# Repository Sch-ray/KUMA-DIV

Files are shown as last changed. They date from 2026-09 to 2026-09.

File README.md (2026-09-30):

# <center>KUMA-DIV
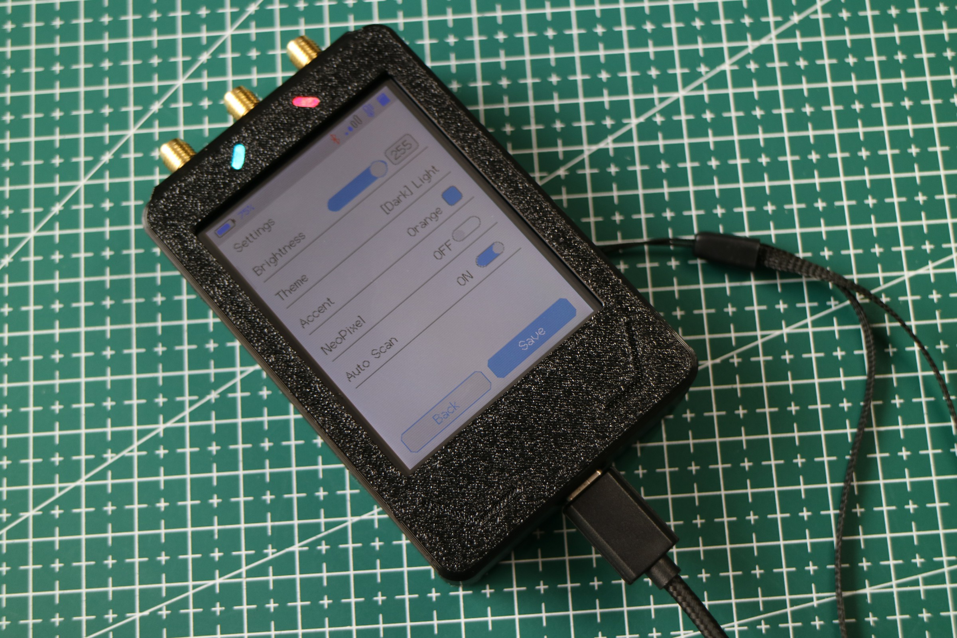
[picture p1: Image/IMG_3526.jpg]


Welcome, and thank you for your support! This is the public repository for the KUMA-DIV project.

****Project Origin****

The KUMA-DIV project is based on https://github.com/cifertech/ESP32-DIV, with the following major differences:

1. KUMA-DIV completely redefines the hardware connections, fixes several pin conflicts, and redesigns the entire PCB.

2. The design makes full use of the touchscreen, eliminating most physical buttons and significantly reducing the overall size.

3. An RGB indicator LED and a buzzer have been reintroduced.

> [!IMPORTANT]

> Disclaimer: This device is intended for lawful technical research, learning, and analysis/testing by qualified users only. (You should know what you're doing.)

****Getting Started****

There is a button on the right side of the device. Press it once briefly to power the device on, or press it twice briefly to power it off.

There are two indicator LEDs on the top of the device. The one on the left is a software-controllable RGB LED, while the one on the right is the charging indicator (red while charging, off when fully charged).

There is a Type-C port on the bottom of the device, which can be used for charging and debugging. It features an integrated CH340 USB-to-serial chip and an automatic ESP32 programming circuit.

There are six antenna ports on the top of the device. Here is what each port is used for. You can refer to the image below when installing the antennas.

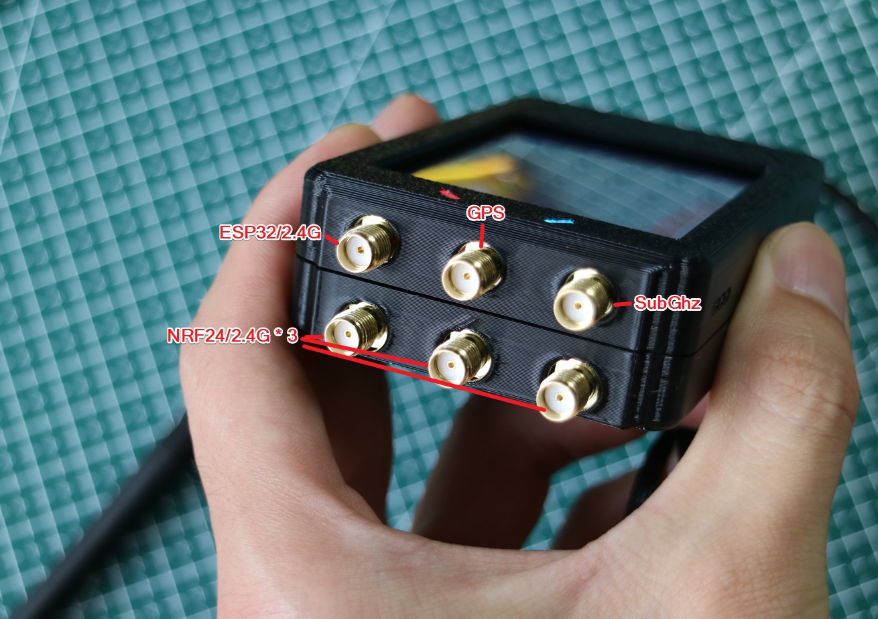
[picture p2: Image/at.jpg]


****Project Files****

[Shell_Modell](./Shell_Model)

The enclosure model files are currently available. You can now 3D-print your own enclosure and make it more stylish ⭐ and more personalized 😎!

[Software](./Software)

The source code is now available. You can build the project yourself, and a detailed compilation guide is also included in the directory 🔨!

****Contact Me****

This is my Tindie store:

[Tindie]https://www.tindie.com/stores/wensley/

If you are interested in collaboration or have suggestions regarding the project, feel free to contact me by email:

[Email]xiao_hei666@yeah.net

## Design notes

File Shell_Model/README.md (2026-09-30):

Welcome, and thank you for your support! If you have a 3D printer, you can now print your own enclosure and make it more stylish ⭐ and more personalized 😎! If you have enough time, you can also choose a finer print resolution for a more detailed result.

Next, I will explain how to assemble the enclosure. If you live in a hot climate, or if the device may be exposed to direct sunlight or high temperatures, PETG or another higher-temperature filament is recommended.

**### Before You Start Printing Your Own Enclosure:**

1. Replacing and installing the enclosure requires some hands-on skills. Any consequences caused by improper operation are your own responsibility. However, since you already have the ability to operate a 3D printer, I believe you can handle it.

2. Make sure the print bed of your 3D printer is clean and has good adhesion, as printing narrow lines and small characters places higher demands on the print bed.

**### File Description:**

This directory contains 2 main enclosure parts: the top shell, the bottom shell, and the light guides.

The light guides must be printed using transparent material.

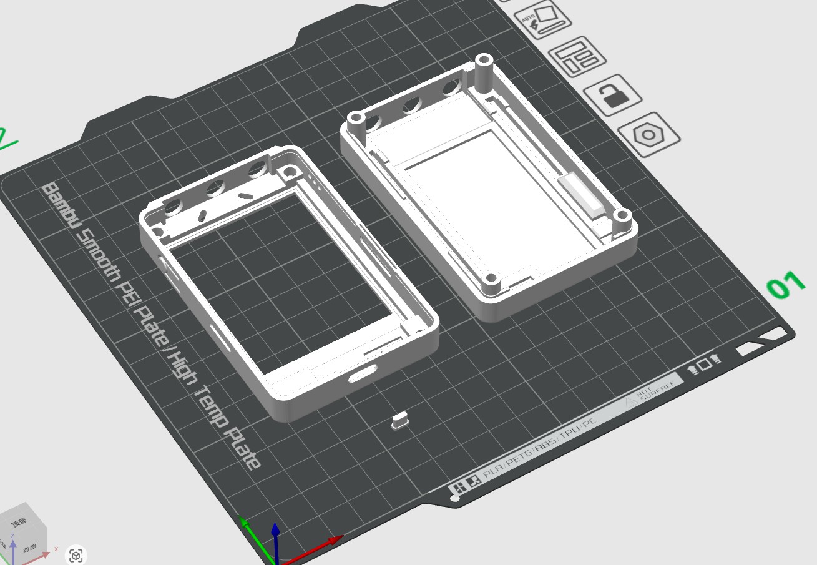
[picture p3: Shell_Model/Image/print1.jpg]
print_view_1


**### Disassembly and Assembly Instructions:**

> [!TIP]
> Before disassembly, you can touch a nearby grounded metal object or use an anti-static wrist strap to prevent electrostatic discharge from damaging the circuit board.

****1. Installing the Light Guides and Heat-Set Nuts****

Use a hammer to gently tap the light guides into the holes, making sure the front surface is flush with the enclosure. Then heat the nuts and press them into the corresponding holes. The final result should look like the pictures below:

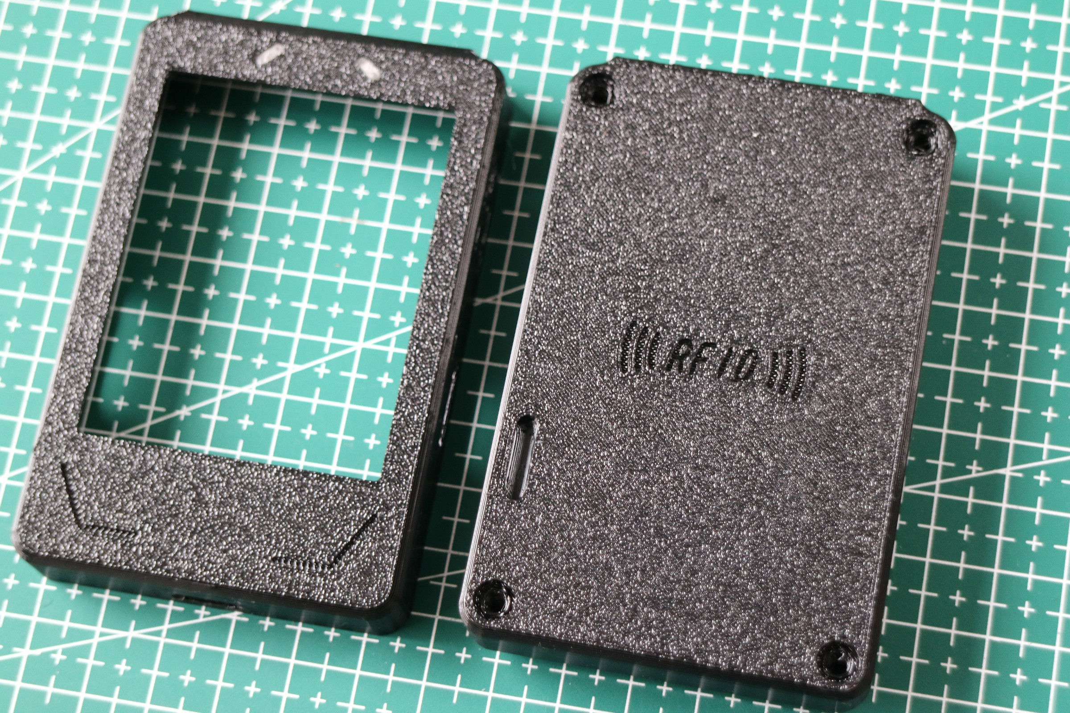
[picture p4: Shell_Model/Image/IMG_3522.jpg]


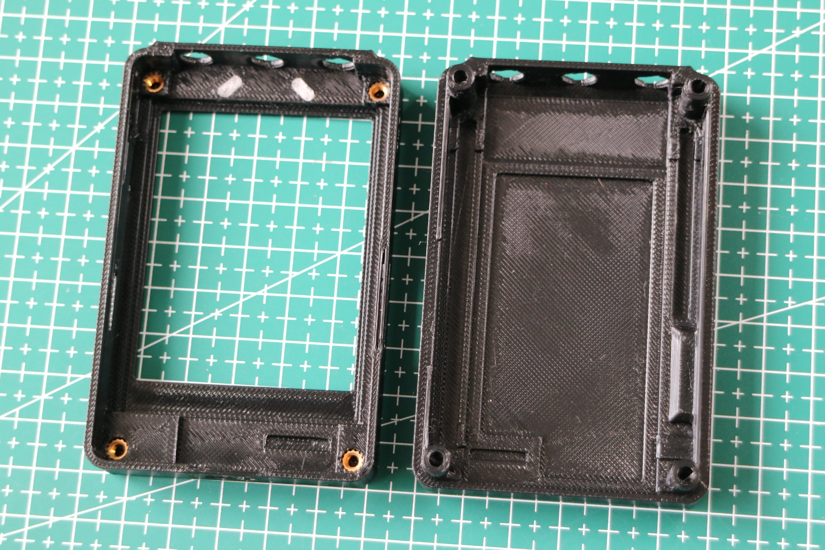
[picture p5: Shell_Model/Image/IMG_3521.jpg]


****2. Installing the RFID/NFC Module****

Before installation, you need to cut off the protruding header pins shown in the picture. As shown below, I removed two of them so you can see the difference in height.

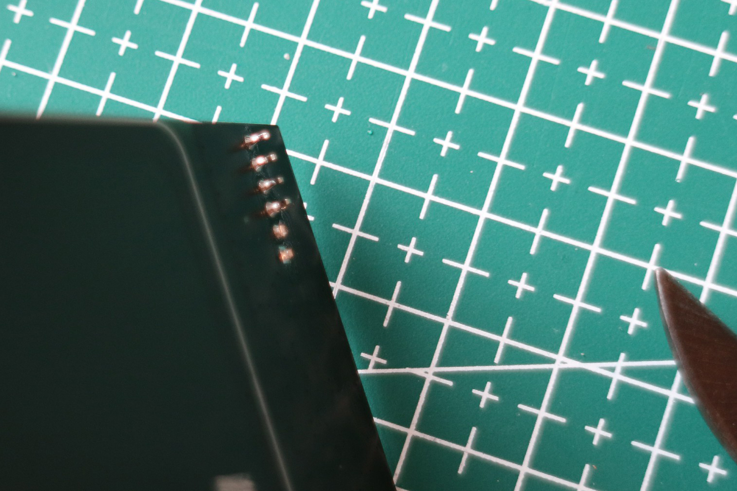
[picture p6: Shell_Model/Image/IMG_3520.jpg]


First, insert the antenna connector through the hole, then press the circuit board into the position shown in the picture. There are four clips around the circuit board. Press firmly to make sure the board is securely locked in place.

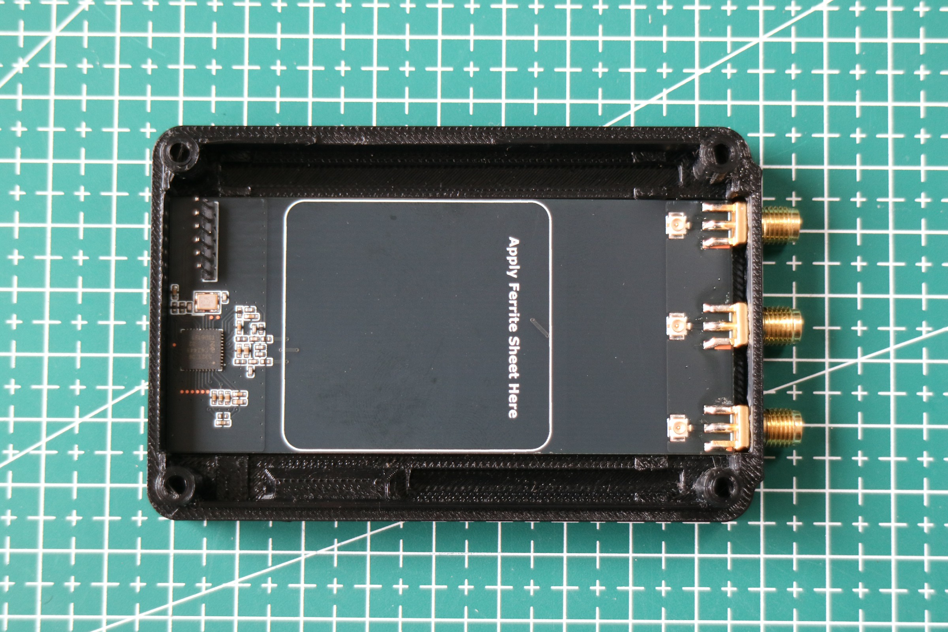
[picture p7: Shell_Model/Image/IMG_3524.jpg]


Attach the magnetic shielding sticker to the area inside the white rectangle. (The size may vary slightly; just make sure it covers the white border.) Then use double-sided tape to secure the battery to the magnetic shielding material.

<div>
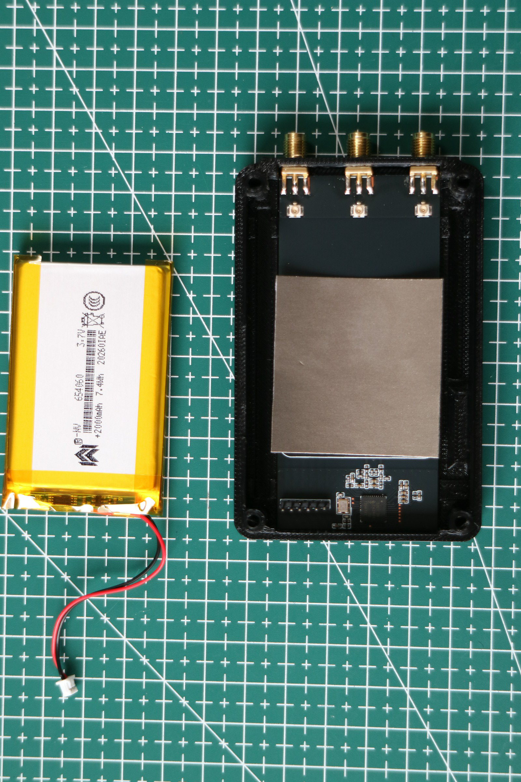
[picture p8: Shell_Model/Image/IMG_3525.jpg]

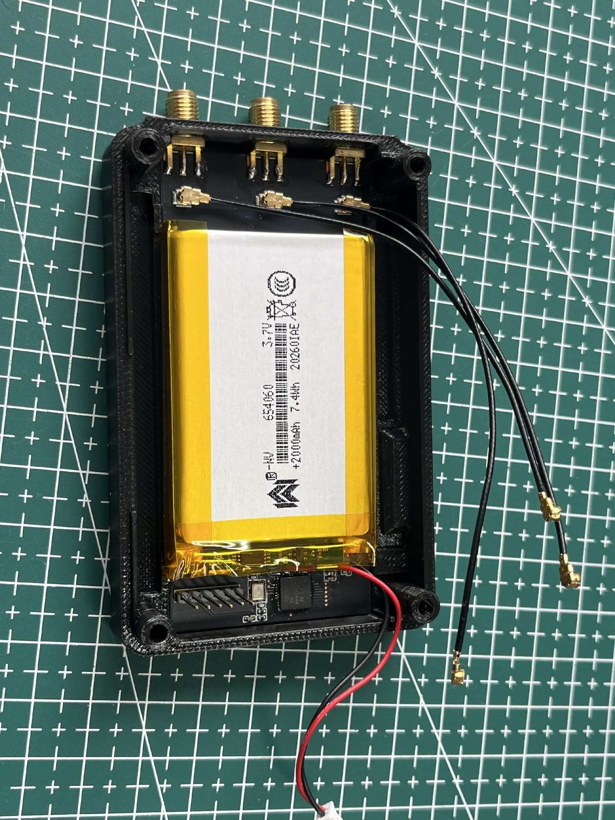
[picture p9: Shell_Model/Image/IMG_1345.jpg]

</div>

Finally, connect the antenna extension cable to the position shown in the picture.

****3. Installing the Main Board****

When installing the main board, first insert the antenna connector through the hole, then press the board into place. Make sure that the screen is properly aligned with the enclosure. Do not use excessive force, as this may damage the screen.

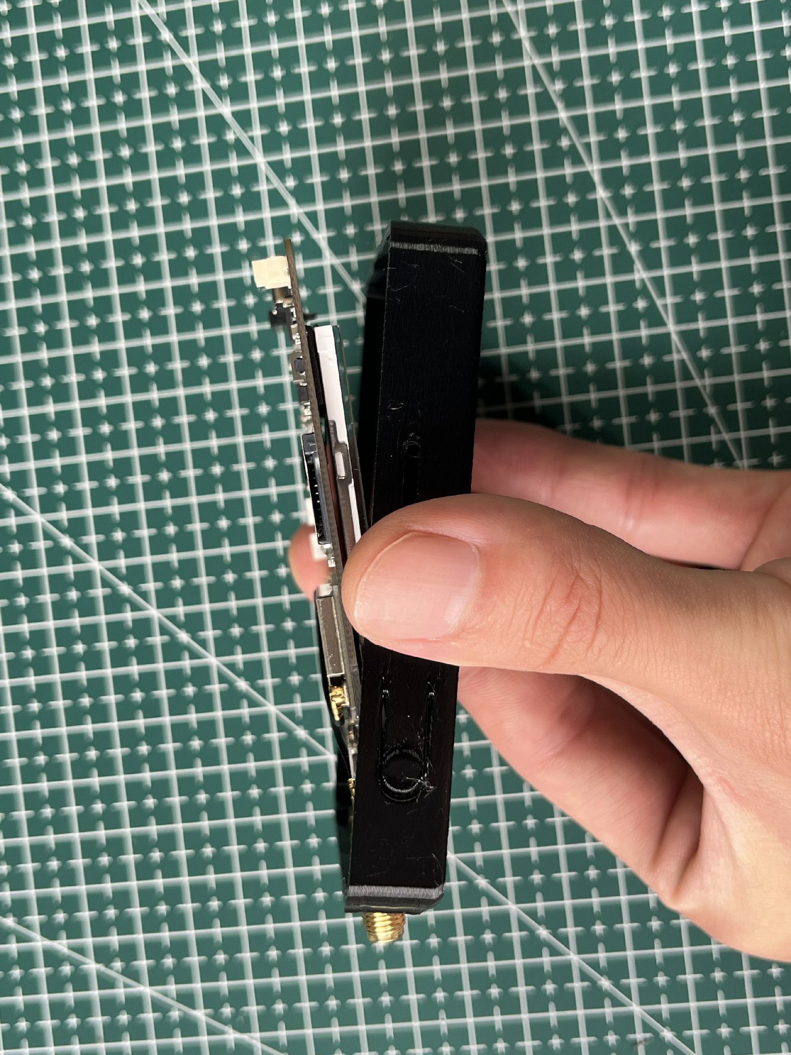
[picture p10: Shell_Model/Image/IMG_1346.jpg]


Connect the extension coil cable to the main board.

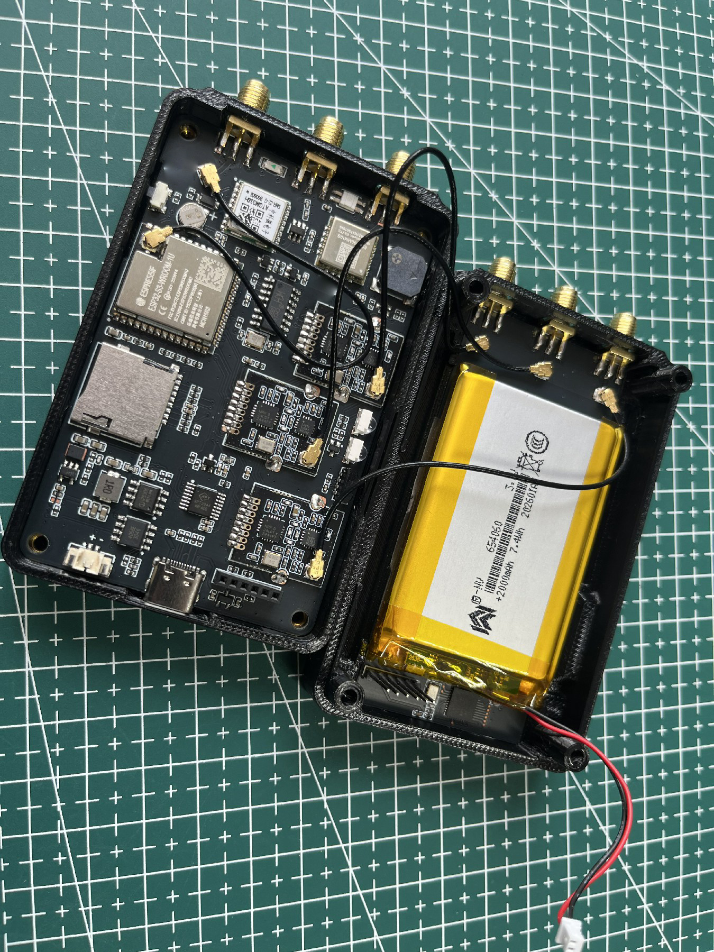
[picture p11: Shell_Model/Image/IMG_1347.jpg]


You can choose to ignore the infrared area on the side, or install a piece of transparent material over it for dust protection. Finally, install the screws, and you're done!

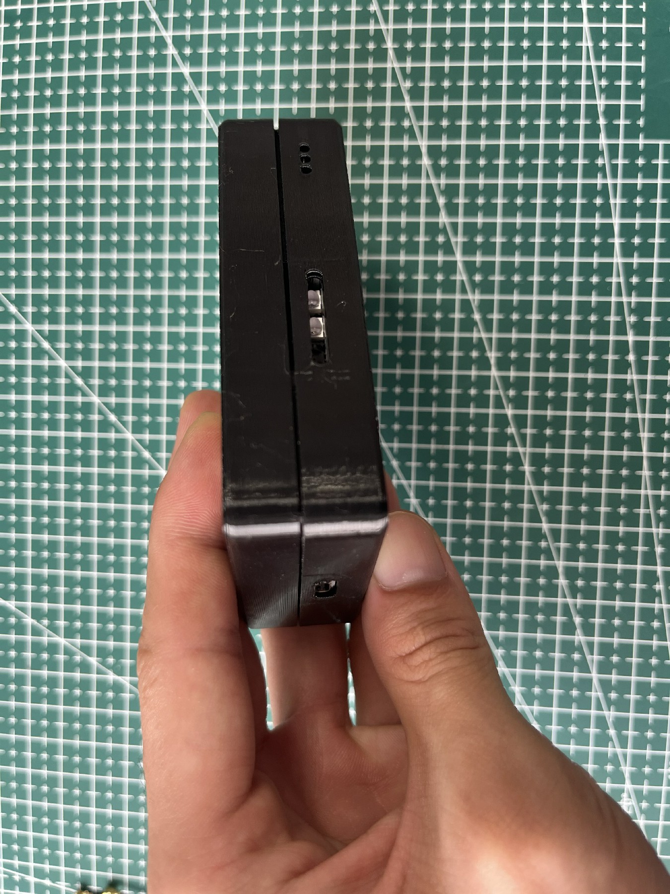
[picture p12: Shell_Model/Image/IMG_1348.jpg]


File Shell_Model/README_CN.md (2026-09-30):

欢迎来到这里，感谢大家支持，如果你有一台3D打印机，现在你可以为自己打印更漂亮⭐更具个人特色😎的外壳!并且如果你有足够的时间，可以选择更精细的打印精度。

接下来我会为你解释如何组装外壳。如果你所在的地区温度较高，或者设备有可能会被曝晒，建议使用PETG或者更高温度的耗材。

### 开始打印自己的外壳前，你需要知道：
1、更换和安装外壳需要一定的动手能力看，因为操作失误的后果，由你自己承担，不过既然你已经有能力操作3D打印机，我相信你是可以搞定的。

2、确保3D打印机的打印板干净，富有粘性，因为打印一些窄线条和字符的时候，对打印板有较高的要求。

### 文件说明：

这个目录包括3个零件：顶部壳体，底部壳体，导光柱。

导光柱必须使用透明材料打印
print_view_1

### 拆卸及组装说明：

> [!TIP]
> 拆卸之前，你可以触摸附近的接地金属，或者使用静电手环，避免静电损坏电路板。

**1、安装导光柱和螺母**

你需要使用锤子将导光柱敲击到孔洞内，确保正面是平整的。然后加热螺母并按压到孔洞内，最终的效果会是图片中的样子：

print_view_1
print_view_1

**2、安装RFID/NFC模块**

在安装之前，你需要将图片中突出的排针剪掉，就像图片中一样，我剪掉了其中两个，你可以看到高度的区别。

Step_1

首先将天线座穿过孔洞，然后将电路板按压到图片中的位置，在电路板四周会有4个卡扣，你需要用力按压，确保牢固。

Step_1

将隔磁贴纸粘贴到白色方框的位置（尺寸可能略有不同，只要能覆盖白色边框即可）。然后使用双面胶将电池固定到隔磁铁的位置。
<div>
  
  
</div>

最后将天线延长线安装到图片中的位置。

**3、安装主板**

安装主板时先将天线座穿过孔洞，然后按压下去即可，你需要注意的是屏幕是否对准了外壳。切记不可使用蛮力，防止压坏屏幕。

Step_1

将延长线圈闭连接到主板上。

Step_1

侧面的红外区域你可以选择忽视，或者安装一些透光材料，只是为了防尘。最后拧上螺丝就大功告成了。

Step_1

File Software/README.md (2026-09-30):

If you just need bin files to download, you can found that in ./output.

And this is download address you need to know:

ESP32-DIV.ino.bootloader.bin -> 0x0

ESP32-DIV.ino.partitions.bin -> 0x8000

ESP32-DIV.ino.bin -> 0x10000

****1. Setting Up the Build Environment****

First, you need to install Arduino IDE. Then install the following dependencies:

ESP32 2.0.10

PCF8574_library-2.3.7

XPT2046_Touchscreen

rc-switch

RF24

arduinoFFT

ArduinoJson

IRremoteESP8266

Adafruit_PN532

Adafruit_BusIO

****2. Replacing Files****

Replace the `platform.txt` file in the following directory with the `platform.txt` provided in the `Libraries` directory:

`C:\Users\user\AppData\Local\Arduino15\packages\esp32\hardware\esp32\2.0.10-cn`

Manually install the `SmartRC-CC1101-Driver-Lib` library from the `Libraries` directory.

Manually install the `TFT_eSPI` library from the `Libraries` directory. You also need to replace its original `User_Setup.h` file with the `User_Setup.h` provided in the `Libraries` directory.

If everything is configured correctly, Arduino should now be able to compile the project successfully.

****3. GPIO Pin Mapping****

The two files you need to pay particular attention to are `config.h` in the project and `User_Setup.h` in the TFT_eSPI installation directory. Make sure that the pin definitions in these files match the following GPIO mapping:

| GPIO | Screen | Touch | TFCard | NRF24_1 | NRF24_2 | NRF24_3 | CC1101 | PN532 | BUZZER/WS2812 | GNSS | IR | IP5306 |
|---|---|---|---|---|---|---|---|---|---|---|----|---|
| IO1  | | | | | | | | | | RX | | |
| IO2  | | | | | | | CS | | | | | |
| IO3  | | | | CE | | | | | | | | |
| IO4  | | | | | | | | CS | | | | |
| IO5  | | | | | | | | | | | | SCL |
| IO6  | | IRQ | | | | | | | | | | |
| IO7  | | CS | | | | | | | | | | |
| IO8  | D/C | | | | | | | | | | | |
| IO9  | | | | | | CSN | | | | | | |
| IO10 | | | | | | CE | | | | | | |
| IO11 | | | | | CSN | | | | | | | |
| IO12 | | | | | CE | | | | | | | |
| IO13 | | | MISO | MISO | MISO | MISO | MISO | MISO  | | | | |
| IO14 | | | MOSI | MOSI | MOSI | MOSI | MOSI | MOSI  | | | | |
| IO15 | | | CS | | | | | | | | | |
| IO16 | MISO | MISO  | | | | | | | | | | |
| IO17 | MOSI | MOSI  | | | | | | | | | | |
| IO18 | CS | | | | | | | | | | | |
| IO19 | SCK | SCK | | | | | | | | | | |
| IO20 | | | | CSN | | | | | | | | |
| IO21 | | | SCK | SCK | SCK | SCK | SCK | SCK | | | | |
| IO38 | | | | | | | | | | | TX | |
| IO39 | | | | | | | | | | | RX | |
| IO40 | | | | | | | | | | | | SDA |
| IO41 | | | | | | | IO0 | | | | | |
| IO42 | | | | | | | IO2 | | | | | |
| IO45 | | | | | | | | | EN/DATA | | | |
| IO46 | BackLight | | | | | | | | | | | |

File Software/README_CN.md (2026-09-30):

如果你只想要最终的固件，你可以在output目录下找到，它们的烧录地址是：

ESP32-DIV.ino.bootloader.bin -> 0x0

ESP32-DIV.ino.partitions.bin -> 0x8000

ESP32-DIV.ino.bin -> 0x10000

**1、安装编译环境**

首先你需要安装arduino。并安装以下依赖库：

ESP32 2.0.10

PCF8574_library-2.3.7

XPT2046_Touchscreen

rc-switch

RF24

arduinoFFT

ArduinoJson

IRremoteESP8266

Adafruit_PN532

Adafruit_BusIO

**2、文件替换**

使用Libraries目录下的platform.txt替换此目录下的同名称文件C:\Users\user\AppData\Local\Arduino15\packages\esp32\hardware\esp32\2.0.10-cn

手动安装Libraries目录下SmartRC-CC1101-Driver-Lib库

手动安装Libraries目录下TFT_eSPI库，并且需要使用Libraries目录下的User_Setup.h替换原有的同名称文件

如果顺利的话arduino现在可以成功编译这个项目

**3、引脚关系**

在项目中，首先需要关注的是config.h和TFT_eSPI安装目录下的User_Setup.h文件，他们需要和引脚保持对应：
| GPIO | Screen | Touch | TFCard | NRF24_1 | NRF24_2 | NRF24_3 | CC1101 | PN532 | BUZZER/WS2812 | GNSS | IR | IP5306 |
|---|---|---|---|---|---|---|---|---|---|---|----|---|
| IO1  | | | | | | | | | | RX | | |
| IO2  | | | | | | | CS | | | | | |
| IO3  | | | | CE | | | | | | | | |
| IO4  | | | | | | | | CS | | | | |
| IO5  | | | | | | | | | | | | SCL |
| IO6  | | IRQ | | | | | | | | | | |
| IO7  | | CS | | | | | | | | | | |
| IO8  | D/C | | | | | | | | | | | |
| IO9  | | | | | | CSN | | | | | | |
| IO10 | | | | | | CE | | | | | | |
| IO11 | | | | | CSN | | | | | | | |
| IO12 | | | | | CE | | | | | | | |
| IO13 | | | MISO | MISO | MISO | MISO | MISO | MISO  | | | | |
| IO14 | | | MOSI | MOSI | MOSI | MOSI | MOSI | MOSI  | | | | |
| IO15 | | | CS | | | | | | | | | |
| IO16 | MISO | MISO  | | | | | | | | | | |
| IO17 | MOSI | MOSI  | | | | | | | | | | |
| IO18 | CS | | | | | | | | | | | |
| IO19 | SCK | SCK | | | | | | | | | | |
| IO20 | | | | CSN | | | | | | | | |
| IO21 | | | SCK | SCK | SCK | SCK | SCK | SCK | | | | |
| IO38 | | | | | | | | | | | TX | |
| IO39 | | | | | | | | | | | RX | |
| IO40 | | | | | | | | | | | | SDA |
| IO41 | | | | | | | IO0 | | | | | |
| IO42 | | | | | | | IO2 | | | | | |
| IO45 | | | | | | | | | EN/DATA | | | |
| IO46 | BackLight | | | | | | | | | | | |

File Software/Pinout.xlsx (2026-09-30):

 | Screen | Touch | TFCard | NRF24_1 | NRF24_2 | NRF24_3 | CC1101 | PN532 | BUZZER/WS2812 | GNSS | IR | IP5306
IO0
IO1 |  |  |  |  |  |  |  |  |  | RX
IO2 |  |  |  |  |  |  | CS
IO3 |  |  |  | CE
IO4 |  |  |  |  |  |  |  | CS
IO5 |  |  |  |  |  |  |  |  |  |  |  | SCL
IO6 |  | IRQ
IO7 |  | CS
IO8 | D/C
IO9 |  |  |  |  |  | CSN
IO10 |  |  |  |  |  | CE
IO11 |  |  |  |  | CSN
IO12 |  |  |  |  | CE
IO13 |  |  | MISO | MISO | MISO | MISO | MISO | MISO
IO14 |  |  | MOSI | MOSI | MOSI | MOSI | MOSI | MOSI
IO15 |  |  | CS
IO16 | MISO | MISO
IO17 | MOSI | MOSI
IO18 | CS
IO19 | SCK | SCK
IO20 |  |  |  | CSN
IO21 |  |  | SCK | SCK | SCK | SCK | SCK | SCK
IO22
IO23
IO24
IO25
IO26
IO27
IO28
IO29
IO30
IO31
IO32
IO33
IO34
IO35 |  |  |  |  |  |  |  |  |  |  |  |  | Save for PSRAM
IO36 |  |  |  |  |  |  |  |  |  |  |  |  | Save for PSRAM
IO37 |  |  |  |  |  |  |  |  |  |  |  |  | Save for PSRAM
IO38 |  |  |  |  |  |  |  |  |  |  | TX
IO39 |  |  |  |  |  |  |  |  |  |  | RX
IO40 |  |  |  |  |  |  |  |  |  |  |  | SDA
IO41 |  |  |  |  |  |  | IO0
IO42 |  |  |  |  |  |  | IO2
IO43
IO44
IO45 |  |  |  |  |  |  |  |  | EN/DATA |  |  |  | Don't Pull Up while boot
IO46 | BackLight |  |  |  |  |  |  |  |  |  |  |  | Don't Pull Up while boot
IO47 |  |  |  |  |  |  |  |  |  |  |  |  | Low Voltage
IO48 |  |  |  |  |  |  |  |  |  |  |  |  | Low Voltage

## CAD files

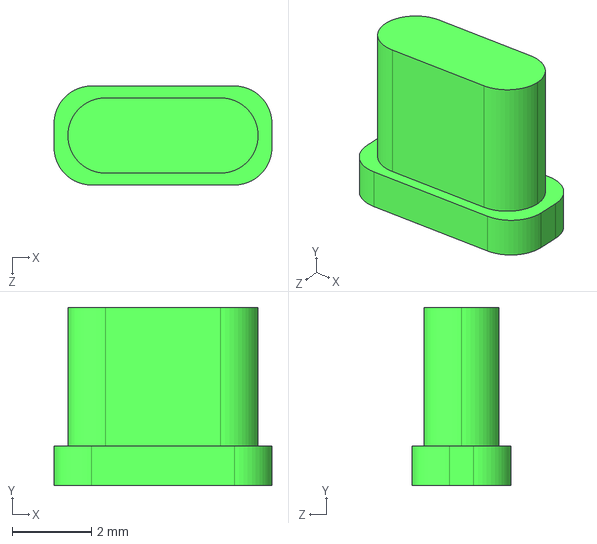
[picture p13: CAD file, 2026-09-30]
Shell_Model/Light.STEP
5.50 x 4.50 x 2.50 mm

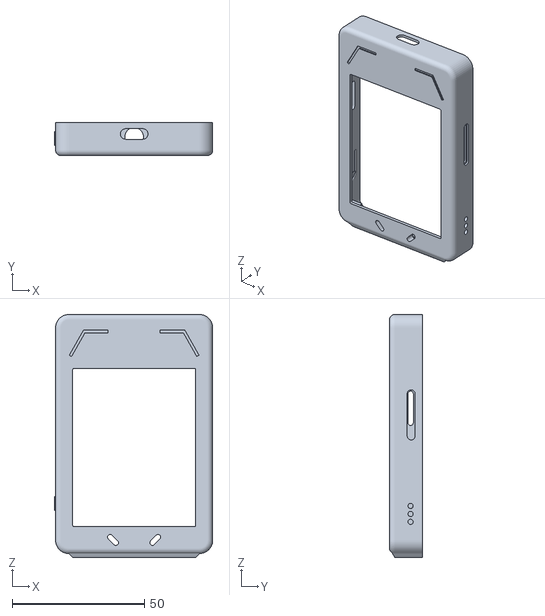
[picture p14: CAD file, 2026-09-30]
Shell_Model/Top.STL
60.0 x 12.5 x 92.0

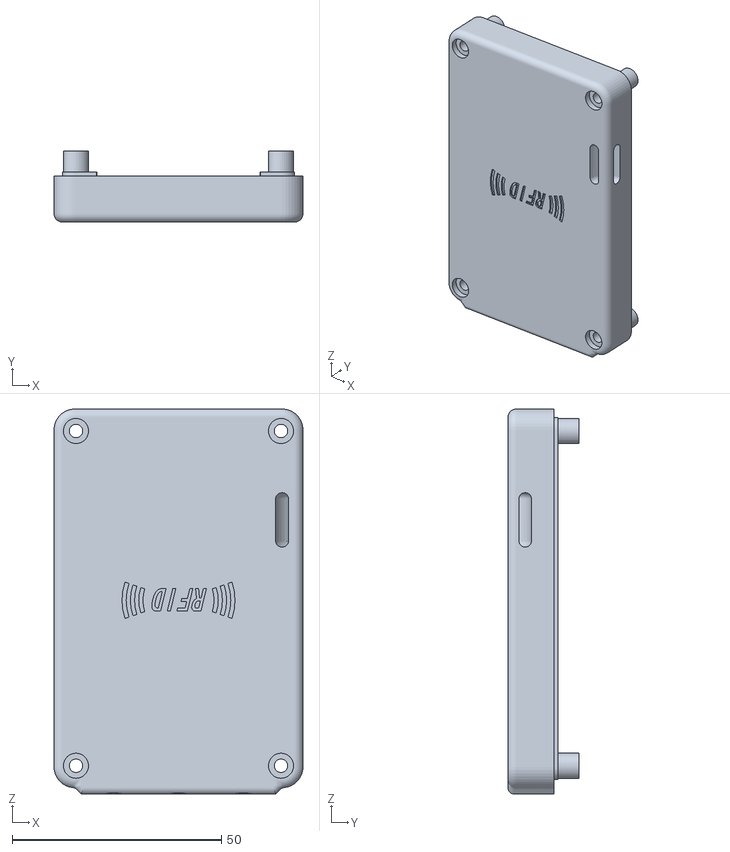
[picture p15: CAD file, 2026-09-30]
Shell_Model/Bottom.STL
59.5 x 17.0 x 92.0

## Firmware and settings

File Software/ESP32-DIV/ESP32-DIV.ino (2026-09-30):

#include <Arduino.h>
#include <PCF8574.h>
#include <TFT_eSPI.h>
#include <Wire.h>
#include "SettingsStore.h"
#include "Touchscreen.h"
#include "config.h"
#include "ducky.h"
#include "icon.h"
#include "ir.h"
#include "gps.h"
#include "rfid.h"
#include "shared.h"
#include "utils.h"
#include <Adafruit_NeoPixel.h>

#if !BOARD_HAS_ESP32S3
#include "soc/soc.h"
#include "soc/rtc_cntl_reg.h"
#endif

extern bool has_ip5306;

Adafruit_NeoPixel strip(1, RGB_DATA, NEO_GRB + NEO_KHZ800);

TFT_eSPI tft = TFT_eSPI();

PCF8574 pcf(PCF8574_I2C_ADDR);

void setBrightness(uint8_t value) {
  ledcWrite(PWM_CHANNEL, value);
}

bool feature_exit_requested = false;

const int NUM_MENU_ITEMS = 8;
const char *menu_items[NUM_MENU_ITEMS] = {
    "WiFi",
    "2.4GHz",
    "More",
    "Settings",
    "Bluetooth",
    "SubGHz",
    "Tools",
    "About"};

const unsigned char *bitmap_icons[NUM_MENU_ITEMS] = {
    bitmap_icon_wifi,
    bitmap_icon_jammer,
    bitmap_icon_dialog,
    bitmap_icon_setting,
    bitmap_icon_spoofer,
    bitmap_icon_analyzer,
    bitmap_icon_stat,
    bitmap_icon_question};

int current_menu_index = 0;
bool is_main_menu = false;

const int NUM_SUBMENU_ITEMS = 12;
const char *submenu_items[NUM_SUBMENU_ITEMS] = {
    "Packet Monitor",
    "Beacon Spammer",
    "WiFi Deauther",
    "Probe Request Flood",
    "Deauth Detector",
    "WiFi Scanner",
    "Captive Portal",
    "Hidden SSID Revealer",
    "WPS Scanner",
    "ARP Scanner",
    "Karma Attack",
    "Back to Main Menu"};

// WiFi submenu is split across two pages (features after Hidden SSID on page 2).
// Bottom row: icon | Main Menu                 Next/Prev Page | icon
static constexpr int WIFI_PAGE0_FEATURES = 8;
static constexpr int WIFI_PAGE1_FEATURES = 3;
static int wifi_submenu_page = 0;

const char *wifi_page0_items[WIFI_PAGE0_FEATURES] = {
    "Packet Monitor",
    "Beacon Spammer",
    "WiFi Deauther",
    "Probe Request Flood",
    "Deauth Detector",
    "WiFi Scanner",
    "Captive Portal",
    "Hidden SSID Revealer"};

const char *wifi_page1_items[WIFI_PAGE1_FEATURES] = {
    "WPS Scanner",
    "ARP Scanner",
    "Karma Attack"};

// Bluetooth submenu uses the same paged footer layout as WiFi.
static constexpr int BT_PAGE0_FEATURES = 8;
static constexpr int BT_PAGE1_FEATURES = 1;
static int bluetooth_submenu_page = 0;

const char *bluetooth_page0_items[BT_PAGE0_FEATURES] = {
    "BLE Jammer",
    "BLE Spoofer",
    "Sour Apple",
    "AirTag Spoofer",
    "AirTag Sniffer",
    "Sniffer",
    "BLE Scanner",
    "BLE Rubber Ducky"};

const char *bluetooth_page1_items[BT_PAGE1_FEATURES] = {
    "Skimmer Detect"};

static FeatureUI::Button s_pagedFooterBtns[2];
static int s_pagedFooterFocus = -1;  // 0=back, 1=page btn, -1=none

const int nrf_NUM_SUBMENU_ITEMS = 7;
const char *nrf_submenu_items[nrf_NUM_SUBMENU_ITEMS] = {
    "Scanner",
    "Proto Kill",
    "ESB Sniffer",
    "ESB Replay",
    "MouseJack Scan",
    "MouseJack Inject",
    "Back to Main Menu"};

const int subghz_NUM_SUBMENU_ITEMS = 6;
const char *subghz_submenu_items[subghz_NUM_SUBMENU_ITEMS] = {
    "Replay Attack",
    "SubGHz Jammer",
    "De Bruijn / Brute",
    "Jamming Detector",
    "Saved Profile",
    "Back to Main Menu"};

const int tools_NUM_SUBMENU_ITEMS = 5;
const char *tools_submenu_items[tools_NUM_SUBMENU_ITEMS] = {
    "Serial Monitor",
    "Update Firmware",
    "Touch Calibrate",
    "SD File Manager",
    "Back to Main Menu"};

static constexpr uint8_t OTHER_LAYER_HOME = 0;
static constexpr uint8_t OTHER_LAYER_IR   = 1;
static constexpr uint8_t OTHER_LAYER_RFID = 2;
static constexpr uint8_t OTHER_LAYER_GPS  = 3;

const int other_NUM_SUBMENU_ITEMS = 4;
static constexpr int OTHER_GRID_COLS = 2;
const char *other_submenu_items[other_NUM_SUBMENU_ITEMS] = {
    "IR Remote",
    "RFID/NFC",
    "GPS",
    "Main Menu"};

const int rfid_NUM_SUBMENU_ITEMS = 9;
const char *rfid_submenu_items[rfid_NUM_SUBMENU_ITEMS] = {
    "Card Reader",
    "Card Clone",
    "Erase",
    "Dump",
    "Decode Access",
    "Jam Reader",
    "Tag Disrupt",
    "Disrupt Emulate",
    "Back to Main Menu"};

const int gps_NUM_SUBMENU_ITEMS = 3;
const char *gps_submenu_items[gps_NUM_SUBMENU_ITEMS] = {
    "Wardriver",
    "Satellite Scanner",
    "Back to Main Menu"};

const int ir_NUM_SUBMENU_ITEMS = 4;
const char *ir_submenu_items[ir_NUM_SUBMENU_ITEMS] = {
    "Record",
    "Saved Profile",
    "Universal Controller",
    "Back to Main Menu"};

const int about_NUM_SUBMENU_ITEMS = 1;
const char *about_submenu_items[about_NUM_SUBMENU_ITEMS] = {
    "Back to Main Menu"};

const int setting_NUM_SUBMENU_ITEMS = 1;
const char *setting_submenu_items[setting_NUM_SUBMENU_ITEMS] = {
    "Back to Main Menu"};

int current_submenu_index = 0;
bool in_sub_menu = false;
int last_submenu_index = -1;
bool submenu_initialized = false;
uint8_t other_layer = OTHER_LAYER_HOME;
int last_other_menu_index = -1;
bool other_menu_grid_initialized = false;

const char **active_submenu_items = nullptr;
int active_submenu_size = 0;

const unsigned char *wifi_submenu_icons[NUM_SUBMENU_ITEMS] = {
    bitmap_icon_wifi,
    bitmap_icon_antenna,
    bitmap_icon_wifi_jammer,
    bitmap_icon_Skull_3,
    bitmap_icon_eye2,
    bitmap_icon_jammer,
    bitmap_icon_bash,
    bitmap_icon_eye_blind,
    bitmap_icon_key,
    bitmap_icon_list,
    bitmap_icon_devil,
    bitmap_icon_go_back
};

const unsigned char *wifi_page0_icons[WIFI_PAGE0_FEATURES] = {
    bitmap_icon_wifi,
    bitmap_icon_antenna,
    bitmap_icon_wifi_jammer,
    bitmap_icon_Skull_3,
    bitmap_icon_eye2,
    bitmap_icon_jammer,
    bitmap_icon_bash,
    bitmap_icon_eye_blind
};

const unsigned char *wifi_page1_icons[WIFI_PAGE1_FEATURES] = {
    bitmap_icon_key,
    bitmap_icon_list,
    bitmap_icon_devil
};

const unsigned char *bluetooth_page0_icons[BT_PAGE0_FEATURES] = {
    bitmap_icon_ble_jammer,
    bitmap_icon_spoofer,
    bitmap_icon_apple,
    bitmap_icon_tags,
    bitmap_icon_magnifying_glass,
    bitmap_icon_analyzer,
    bitmap_icon_graph,
    bitmap_icon_rubber_ducky
};

const unsigned char *bluetooth_page1_icons[BT_PAGE1_FEATURES] = {
    bitmap_icon_Wireless_4
};

const unsigned char *nrf_submenu_icons[nrf_NUM_SUBMENU_ITEMS] = {
    bitmap_icon_scanner,
    bitmap_icon_kill,
    bitmap_icon_analyzer,
    bitmap_icon_follow,
    bitmap_icon_magnifying_glass,
    bitmap_icon_key,
    bitmap_icon_go_back
};

const unsigned char *subghz_submenu_icons[subghz_NUM_SUBMENU_ITEMS] = {
    bitmap_icon_antenna,
    bitmap_icon_no_signal,
    bitmap_icon_graph_self_loop,
    bitmap_icon_Voice_Id,
    bitmap_icon_list,
    bitmap_icon_go_back
};

const unsigned char *tools_submenu_icons[tools_NUM_SUBMENU_ITEMS] = {
    bitmap_icon_bash,
    bitmap_icon_follow,
    bitmap_icon_undo,
    bitmap_icon_sdcard,
    bitmap_icon_go_back
};

const unsigned char *other_submenu_icons[other_NUM_SUBMENU_ITEMS] = {
    bitmap_icon_led,
    bitmap_icon_rfid_chip,
    bitmap_icon_satellite,
    bitmap_icon_go_back
};

const unsigned char *rfid_submenu_icons[rfid_NUM_SUBMENU_ITEMS] = {
    bitmap_icon_magnifying_glass,
    bitmap_icon_follow,
    bitmap_icon_recycle,
    bitmap_icon_dot_matrix,
    bitmap_icon_key,
    bitmap_icon_kill,
    bitmap_icon_flash,
    bitmap_icon_devil,
    bitmap_icon_go_back
};

const unsigned char *gps_submenu_icons[gps_NUM_SUBMENU_ITEMS] = {
    bitmap_icon_satellite,
    bitmap_icon_satellite_dish,
    bitmap_icon_go_back
};

const unsigned char *ir_submenu_icons[ir_NUM_SUBMENU_ITEMS] = {
    bitmap_icon_led,
    bitmap_icon_list,
    bitmap_icon_remote_control,
    bitmap_icon_go_back
};

const unsigned char *about_submenu_icons[about_NUM_SUBMENU_ITEMS] = {
    bitmap_icon_go_back
};

const unsigned char *setting_submenu_icons[setting_NUM_SUBMENU_ITEMS] = {
    bitmap_icon_go_back
};

const unsigned char **active_submenu_icons = nullptr;

static int wifiFeatureCount() {
    return (wifi_submenu_page == 0) ? WIFI_PAGE0_FEATURES : WIFI_PAGE1_FEATURES;
}

static int bluetoothFeatureCount() {
    return (bluetooth_submenu_page == 0) ? BT_PAGE0_FEATURES : BT_PAGE1_FEATURES;
}

static int pagedFeatureCount() {
    if (current_menu_index == 4) {
        return bluetoothFeatureCount();
    }
    return wifiFeatureCount();
}

static int* pagedSubmenuPage() {
    return (current_menu_index == 4) ? &bluetooth_submenu_page : &wifi_submenu_page;
}

// Bottom row: [icon | Main Menu] ........ [Next/Prev Page | icon]
static int pagedBackBtnIndex() {
    return pagedFeatureCount();
}

static int pagedPageBtnIndex() {
    return pagedFeatureCount() + 1;
}

static int pagedNavRowY() {
    return tft.height() - 30;
}

static const char* pagedPageBtnLabel() {
    return (*pagedSubmenuPage() == 0) ? "Next Page" : "Prev Page";
}

static const unsigned char* pagedPageBtnIcon() {
    return (*pagedSubmenuPage() == 0) ? bitmap_icon_navigate_right : bitmap_icon_navigate_left;
}

static void layoutPagedFooterButtons() {
    const int y = pagedNavRowY();
    const int mid = tft.width() / 2;
    s_pagedFooterBtns[0] = {
        0, (int16_t)y, (int16_t)mid, 28,
        "Main Menu", FeatureUI::ButtonStyle::Secondary, false};
    s_pagedFooterBtns[1] = {
        (int16_t)mid, (int16_t)y, (int16_t)(tft.width() - mid), 28,
        pagedPageBtnLabel(), FeatureUI::ButtonStyle::Secondary, false};
}

static void drawPagedFooterButtons() {
    layoutPagedFooterButtons();
    const int y = pagedNavRowY();
    const int rowH = 28;
    const int iconSize = 16;
    tft.fillRect(0, y, tft.width(), rowH, UI_BG);

    tft.setTextDatum(TL_DATUM);
    tft.setTextFont(2);
    tft.setTextSize(1);
    // Font 2 is ~16px; center icon + text on the same midline within the row.
    const int textH = 16;
    const int iconY = y + (rowH - iconSize) / 2;
    const int textY = y + (rowH - textH) / 2;

    {
        const uint16_t color = (s_pagedFooterFocus == 0) ? UI_ICON : UI_TEXT;
        tft.setTextColor(color, UI_BG);
        tft.drawBitmap(10, iconY, bitmap_icon_go_back, iconSize, iconSize, color);
        tft.setCursor(30, textY);
        tft.print("Main Menu");
    }

    {
        const uint16_t color = (s_pagedFooterFocus == 1) ? UI_ICON : UI_TEXT;
        const char* label = pagedPageBtnLabel();
        const int gap = 4;
        const int textW = tft.textWidth(label);
        // Right-aligned group: [label][gap][icon] — same vertical midline.
        const int iconX = tft.width() - 10 - iconSize;
        const int textX = iconX - gap - textW;
        tft.setTextColor(color, UI_BG);
        tft.setCursor(textX, textY);
        tft.print(label);
        tft.drawBitmap(iconX, iconY, pagedPageBtnIcon(), iconSize, iconSize, color);
    }
}

static void applyWifiSubmenuPage() {
    if (wifi_submenu_page == 0) {
        active_submenu_items = wifi_page0_items;
        active_submenu_icons = wifi_page0_icons;
    } else {
        active_submenu_items = wifi_page1_items;
        active_submenu_icons = wifi_page1_icons;
    }
    active_submenu_size = wifiFeatureCount() + 2;
    if (current_submenu_index >= active_submenu_size) {
        current_submenu_index = 0;
    }
    s_pagedFooterFocus = -1;
    last_submenu_index = -1;
    submenu_initialized = false;
}

static void applyBluetoothSubmenuPage() {
    if (bluetooth_submenu_page == 0) {
        active_submenu_items = bluetooth_page0_items;
        active_submenu_icons = bluetooth_page0_icons;
    } else {
        active_submenu_items = bluetooth_page1_items;
        active_submenu_icons = bluetooth_page1_icons;
    }
    active_submenu_size = bluetoothFeatureCount() + 2;
    if (current_submenu_index >= active_submenu_size) {
        current_submenu_index = 0;
    }
    s_pagedFooterFocus = -1;
    last_submenu_index = -1;
    submenu_initialized = false;
}

void updateActiveSubmenu() {
    switch (current_menu_index) {
        case 0:
            wifi_submenu_page = 0;
            current_submenu_index = 0;
            applyWifiSubmenuPage();
            break;
        case 1:
            active_submenu_items = nrf_submenu_items;
            active_submenu_size = nrf_NUM_SUBMENU_ITEMS;
            active_submenu_icons = nrf_submenu_icons;
            break;
        case 2:
            if (other_layer == OTHER_LAYER_HOME) {
                active_submenu_items = other_submenu_items;
                active_submenu_size = other_NUM_SUBMENU_ITEMS;
                active_submenu_icons = other_submenu_icons;
            } else if (other_layer == OTHER_LAYER_IR) {
                active_submenu_items = ir_submenu_items;
                active_submenu_size = ir_NUM_SUBMENU_ITEMS;
                active_submenu_icons = ir_submenu_icons;
            } else if (other_layer == OTHER_LAYER_RFID) {
                active_submenu_items = rfid_submenu_items;
                active_submenu_size = rfid_NUM_SUBMENU_ITEMS;
                active_submenu_icons = rfid_submenu_icons;
            } else if (other_layer == OTHER_LAYER_GPS) {
                active_submenu_items = gps_submenu_items;
                active_submenu_size = gps_NUM_SUBMENU_ITEMS;
                active_submenu_icons = gps_submenu_icons;
            } else {
                active_submenu_items = other_submenu_items;
                active_submenu_size = other_NUM_SUBMENU_ITEMS;
                active_submenu_icons = other_submenu_icons;
            }
            break;
        case 3:
            active_submenu_items = nullptr;
            active_submenu_size = 0;
            active_submenu_icons = nullptr;
            break;
        case 4:
            bluetooth_submenu_page = 0;
            current_submenu_index = 0;
            applyBluetoothSubmenuPage();
            break;
        case 5:
            active_submenu_items = subghz_submenu_items;
            active_submenu_size = subghz_NUM_SUBMENU_ITEMS;
            active_submenu_icons = subghz_submenu_icons;
            break;
        case 6:
            active_submenu_items = tools_submenu_items;
            active_submenu_size = tools_NUM_SUBMENU_ITEMS;
            active_submenu_icons = tools_submenu_icons;
            break;
        case 7:
            active_submenu_items = nullptr;
            active_submenu_size = 0;
            active_submenu_icons = nullptr;
            break;

        default:
            active_submenu_items = nullptr;
            active_submenu_size = 0;
            active_submenu_icons = nullptr;
            break;
    }
}

static bool touchButtonInputEnabled = false;
static bool touchButtonCueDrawn = false;
static bool s_touchNavLabelsConfigured = false;
static bool s_touchNavHeld[5] = {false, false, false, false, false};
#if HAS_PCF8574_BUTTONS
static bool s_pcfButtonLastState[8] = {true, true, true, true, true, true, true, true};
#endif
static FeatureUI::Button s_touchNavBtns[5];
static const char* s_touchNavLabels[5] = {nullptr, nullptr, nullptr, nullptr, nullptr};
static constexpr int16_t TOUCH_NAV_BAR_H = (FeatureUI::FOOTER_H * 4) / 5;  // 20% shorter than footer

static int touchNavPinForIndex(int idx) {
  switch (idx) {
    case 0: return BTN_LEFT;
    case 1: return BTN_DOWN;
    case 2: return BTN_SELECT;
    case 3: return BTN_UP;
    case 4: return BTN_RIGHT;
    default: return -1;
  }
}

void setTouchButtonInputEnabled(bool enabled) {
  if (touchButtonInputEnabled != enabled) {
    touchButtonCueDrawn = false;
    if (!enabled) {
      for (int i = 0; i < 5; ++i) {
        s_touchNavLabels[i] = nullptr;
      }
      s_touchNavLabelsConfigured = false;
      for (int i = 0; i < 5; ++i) {
        s_touchNavHeld[i] = false;
      }
    }
  }
  touchButtonInputEnabled = enabled;
#if TOUCH_BUTTON_CUE_ENABLED
  if (enabled && feature_active) {
    drawTouchNavBar();
    touchButtonCueDrawn = true;
  }
#endif
}

bool featureHasTouchNavBar() {
#if TOUCH_BUTTON_CUE_ENABLED
  return touchButtonInputEnabled && feature_active;
#else
  return false;
#endif
}

void setTouchNavLabels(const char* left, const char* down, const char* center,
                       const char* up, const char* right) {
  s_touchNavLabels[0] = left;
  s_touchNavLabels[1] = down;
  s_touchNavLabels[2] = center;
  s_touchNavLabels[3] = up;
  s_touchNavLabels[4] = right;
  s_touchNavLabelsConfigured = true;
  invalidateTouchButtonCue();
}

void invalidateTouchButtonCue() {
  touchButtonCueDrawn = false;
}

void resetTouchNavHeldState() {
  for (int i = 0; i < 5; ++i) {
    s_touchNavHeld[i] = false;
  }
}

void redrawTouchButtonBar() {
  invalidateTouchButtonCue();
  drawTouchButtonCue();
}

static void layoutTouchNavBtns() {
  const int barY = tft.height() - TOUCH_NAV_BAR_H;
  const int barH = TOUCH_NAV_BAR_H;
  const int totalW = tft.width();
  const int cellW = totalW / 5;

  for (int i = 0; i < 5; ++i) {
    const int x = i * cellW;
    const int w = (i == 4) ? (totalW - x) : cellW;
    s_touchNavBtns[i] = {
      (int16_t)x, (int16_t)barY, (int16_t)w, (int16_t)barH,
      nullptr, FeatureUI::ButtonStyle::Secondary, false};
  }
}

static String fitTouchNavLabel(const char* label, int maxWidth) {
  if (!label || !label[0]) {
    return String();
  }
  String out = label;
  if (tft.textWidth(out) <= maxWidth) {
    return out;
  }
  while (out.length() > 1 && tft.textWidth(out + "...") > maxWidth) {
    out.remove(out.length() - 1);
  }
  return out + "...";
}

static void drawTouchNavBar() {
  static const unsigned char* kIcons[5] = {
    bitmap_icon_LEFT,
    bitmap_icon_DOWN,
    bitmap_icon_go_back,
    bitmap_icon_UP,
    bitmap_icon_RIGHT,
  };
  constexpr int kIconSize = 16;

  const int barY = tft.height() - TOUCH_NAV_BAR_H;
  const int barH = TOUCH_NAV_BAR_H;
  const int barW = tft.width();

  layoutTouchNavBtns();

  tft.fillRect(0, barY, barW, barH, UI_FG);
  tft.drawFastHLine(0, barY, barW, UI_LINE);

  for (int i = 0; i < 5; ++i) {
    const auto& b = s_touchNavBtns[i];
    if (i > 0) {
      tft.drawFastVLine(b.x, barY + 3, barH - 6, UI_LINE);
    }

    if (s_touchNavLabels[i] && s_touchNavLabels[i][0]) {
      tft.setTextDatum(MC_DATUM);
      const uint16_t txtColor = (i == 2) ? UI_ICON : UI_TEXT;
      tft.setTextColor(txtColor, UI_FG);
      const String fit = fitTouchNavLabel(s_touchNavLabels[i], b.w - 8);
      tft.drawString(fit, b.x + b.w / 2, b.y + b.h / 2, 1);
    } else {
      const int ix = b.x + (b.w - kIconSize) / 2;
      const int iy = b.y + (b.h - kIconSize) / 2;
      const bool inactiveSlot = s_touchNavLabelsConfigured && !s_touchNavLabels[i];
      const unsigned char* icon = inactiveSlot ? bitmap_icon_dots : kIcons[i];
      const uint16_t iconColor = inactiveSlot ? LIGHT_GRAY : ((i == 2) ? UI_ICON : UI_TEXT);
      tft.drawBitmap(ix, iy, icon, kIconSize, kIconSize, iconColor);
    }
  }

  tft.setTextDatum(TL_DATUM);
  tft.setTextFont(1);
  tft.setTextSize(1);
  tft.setTextColor(UI_TEXT, FEATURE_BG);
}

void maintainTouchNavBar() {
#if TOUCH_BUTTON_CUE_ENABLED
  if (!touchButtonInputEnabled || !feature_active || touchButtonCueDrawn) {
    return;
  }
  drawTouchNavBar();
  touchButtonCueDrawn = true;
#endif
}

void featureClearContent(uint16_t color) {
  const int bottom = touchNavContentBottomY();
  if (bottom > 0) {
    tft.fillRect(0, 0, tft.width(), bottom, color);
  } else {
    tft.fillScreen(color);
  }
}

int16_t touchNavReservedHeight() {
#if TOUCH_BUTTON_CUE_ENABLED
  if (touchButtonInputEnabled && feature_active) {
    return TOUCH_NAV_BAR_H;
  }
#endif
  return 0;
}

int16_t touchNavContentBottomY() {
  return (int16_t)(tft.height() - touchNavReservedHeight());
}

void drawTouchButtonCue() {
#if TOUCH_BUTTON_CUE_ENABLED
  if (!touchButtonInputEnabled || !feature_active) {
    return;
  }
  drawTouchNavBar();
  touchButtonCueDrawn = true;
#endif
}

static int touchNavIndexForPin(int buttonPin) {
  for (int i = 0; i < 5; ++i) {
    if (touchNavPinForIndex(i) == buttonPin) {
      return i;
    }
  }
  return -1;
}

static bool isTouchNavSlotDown(int idx) {
  if (idx < 0 || !feature_active || !touchButtonInputEnabled) {
    return false;
  }

  int x = 0;
  int y = 0;
  if (!readTouchXYDismiss(x, y)) {
    return false;
  }

  layoutTouchNavBtns();

  const int stripTop = tft.height() - TOUCH_NAV_BAR_H;
  if (y < stripTop) {
    return false;
  }

  return FeatureUI::hit(s_touchNavBtns, 5, x, y) == idx;
}

bool isPhysicalButtonPressed(int buttonPin) {
#if HAS_PCF8574_BUTTONS
  if (getPcf8574Address() != 0) {
    return !pcf.digitalRead(buttonPin);
  }
#endif
  return false;
}

bool isTouchNavButtonPressed(int buttonPin) {
  const int idx = touchNavIndexForPin(buttonPin);
  if (idx < 0) {
    return false;
  }
  return isTouchNavSlotDown(idx);
}

bool isButtonPressed(int buttonPin) {
  if (isPhysicalButtonPressed(buttonPin)) {
    return true;
  }
  return isTouchNavButtonPressed(buttonPin);
}

bool isTouchNavButtonPressedEdge(int buttonPin) {
  if (!feature_active || !touchButtonInputEnabled) {
    return false;
  }

  const int navIdx = touchNavIndexForPin(buttonPin);
  if (navIdx < 0) {
    return false;
  }

  const bool down = isTouchNavSlotDown(navIdx);
  const bool edge = down && !s_touchNavHeld[navIdx];
  s_touchNavHeld[navIdx] = down;
  return edge;
}

bool isButtonPressedEdge(int buttonPin) {
#if HAS_PCF8574_BUTTONS
  if (getPcf8574Address() != 0) {
    const int idx = buttonPin % 8;
    const bool cur = pcf.digitalRead(buttonPin);
    const bool edge = !cur && s_pcfButtonLastState[idx];
    s_pcfButtonLastState[idx] = cur;
    if (edge) {
      return true;
    }
  }
#endif

  return isTouchNavButtonPressedEdge(buttonPin);
}

bool featureExitButtonPressed() {
  return isPhysicalButtonPressed(BTN_SELECT) || isTouchNavButtonPressed(BTN_SELECT);
}
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
void loop() {
  applyThemeToPalette(settings().theme);
//   Serial.println("[app] 1");
  handleButtons();
//   Serial.println("[app] 2");
  updateStatusBar();
//   Serial.println("[app] 3");
}

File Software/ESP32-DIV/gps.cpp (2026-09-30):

#include <Arduino.h>
#include <HardwareSerial.h>
#include <TFT_eSPI.h>
#include <math.h>
#include <stdint.h>
#include <ctype.h>
#include <stdarg.h>
#include <stdlib.h>
#include <string.h>
#include <string>

#include <WiFi.h>
#include <WiFiClientSecure.h>
#include "mbedtls/base64.h"
#include "freertos/FreeRTOS.h"
#include "freertos/task.h"

#include "BleCompat.h"

#include "gps.h"
#include "icon.h"
#include "KeyboardUI.h"
#include "shared.h"
#include "Touchscreen.h"
#include "utils.h"

#ifndef GPS_UART_NUM
#define GPS_UART_NUM 2
#endif
#ifndef GPS_UART_BAUD
#define GPS_UART_BAUD 9600
#endif

#ifndef M_PI
#define M_PI 3.14159265358979323846
#endif

static HardwareSerial gpsSerial(GPS_UART_NUM);
static TFT_eSprite gScanPanel(&tft);
static bool gScanPanelReady = false;
static int gScanPanelAllocW = 0;
static int gScanPanelAllocH = 0;

static constexpr int kScanSpriteHMin = 200;

static bool ensureScanPanelSprite(int panelW, int panelH) {
  if (panelW <= 0 || panelH <= 32) {
    return false;
  }
  if (gScanPanelReady && panelW == gScanPanelAllocW && gScanPanelAllocH <= panelH &&
      gScanPanelAllocH >= kScanSpriteHMin) {
    return true;
  }

  if (gScanPanelReady) {
    gScanPanel.deleteSprite();
    gScanPanelReady = false;
    gScanPanelAllocW = gScanPanelAllocH = 0;
  }

  for (int h = panelH; h >= kScanSpriteHMin; h -= 18) {
    for (uint8_t bpp : {8, 16}) {
      gScanPanel.setColorDepth(bpp);
      if (gScanPanel.createSprite(panelW, h)) {
        gScanPanelReady = true;
        gScanPanelAllocW = panelW;
        gScanPanelAllocH = h;
        return true;
      }
      delay(20);
    }
  }

  gScanPanel.setColorDepth(16);
  gScanPanelAllocW = gScanPanelAllocH = 0;
  return false;
}

static bool gWardSuppressBottomTouchExit = false;

namespace {

constexpr size_t kLineCap = 128;
constexpr uint32_t kRedrawMs = 450;

constexpr int kGfxTop = 22;
constexpr int kMaxSatRows = 48;
constexpr int kSnrBarMax = 50;

constexpr int kSkyRDefault = 52;
constexpr int kSkyCyDefault = 110;
constexpr int kSkyCyBig = 118;
constexpr int kSkyRBig = 70;
constexpr int kListRowsVisible = 9;

constexpr int kUiPad = 5;
constexpr int kUiGap = 3;
constexpr int kHeaderY = 2;
constexpr int kTabsY = 24;
constexpr int kCardsY = 46;
constexpr int kCardH = 29;
constexpr int kBodyTop = 82;

constexpr uint32_t kNavCooldownMs = 520;

char lineBuf[kLineCap];
size_t lineLen = 0;

enum : uint8_t {
  SYS_GPS = 0,
  SYS_GLO,
  SYS_GAL,
  SYS_BDS,
  SYS_QZS,
  SYS_UNK,
};

struct SatRow {
  uint8_t prn;
  uint8_t system;
  int16_t elev;
  int16_t azim;
  int16_t snr;
  bool inSolution;
};

SatRow rows[kMaxSatRows];
int rowCount = 0;
uint32_t lastGsvMs = 0;

enum class ViewMode : uint8_t { Combined = 0, SkyOnly, ListOnly };
ViewMode viewMode = ViewMode::Combined;
int listScroll = 0;
uint32_t lastViewBtnMs = 0;

static bool prevHwLeft = false;
static bool prevHwRight = false;
static bool prevHwUp = false;
static bool prevHwDown = false;
static bool touchNavArm = true;

char utcStr[12] = "--:--:--";
char dateStr[12] = "--/--/--";
float hdopLive = -1.f;
float pdopLive = -1.f;
uint8_t fixQuality = 0;
uint8_t gsaFixMode = 1;
uint8_t satsUsedGga = 0;
double navLat = NAN;
double navLon = NAN;
float navAltM = NAN;
bool rmcNavValid = false;
uint32_t lastNavMs = 0;

void stripChecksum(char* s) {
  char* star = strchr(s, '*');
  if (star) {
    *star = '\0';
  }
  char* cr = strchr(s, '\r');
  if (cr) {
    *cr = '\0';
  }
}

int splitCommaFields(char* s, const char** fields, int maxFields) {
  int nf = 0;
  fields[nf++] = s;
  for (; *s && nf < maxFields; ++s) {
    if (*s == ',') {
      *s = '\0';
      fields[nf++] = s + 1;
    }
  }
  return nf;
}

uint8_t talkerSystem(char c1, char c2) {
  if (c1 == 'G' && c2 == 'P') {
    return SYS_GPS;
  }
  if (c1 == 'G' && c2 == 'L') {
    return SYS_GLO;
  }
  if (c1 == 'G' && c2 == 'A') {
    return SYS_GAL;
  }
  if (c1 == 'G' && c2 == 'B') {
    return SYS_BDS;
  }
  if (c1 == 'G' && c2 == 'Q') {
    return SYS_QZS;
  }
  if (c1 == 'G' && c2 == 'N') {
    return SYS_GPS;
  }
  return SYS_UNK;
}

const char* systemShortTag(uint8_t sys) {
  switch (sys) {
    case SYS_GPS:
      return "GPS";
    case SYS_GLO:
      return "GLO";
    case SYS_GAL:
      return "GAL";
    case SYS_BDS:
      return "BDS";
    case SYS_QZS:
      return "QZS";
    default:
      return "?";
  }
}

uint16_t baseColorForSystem(uint8_t sys) {
  switch (sys) {
    case SYS_GPS:
      return 0x07FF;
    case SYS_GLO:
      return 0xFA20;
    case SYS_GAL:
      return 0xAFE5;
    case SYS_BDS:
      return ORANGE;
    case SYS_QZS:
      return 0xFC9F;
    default:
      return LIGHT_GRAY;
  }
}

static uint16_t scaleRgb565(uint16_t c, int num, int den) {
  if (den <= 0) {
    return c;
  }
  uint16_t r = ((c >> 11) & 0x1F);
  uint16_t g = ((c >> 5) & 0x3F);
  uint16_t b = (c & 0x1F);
  r = (uint16_t)((r * num) / den);
  g = (uint16_t)((g * num) / den);
  b = (uint16_t)((b * num) / den);
  return (uint16_t)((r << 11) | (g << 5) | b);
}

uint16_t snrTint(uint16_t base, int16_t snr) {
  if (snr < 0) {
    return scaleRgb565(base, 10, 16);
  }
  int k = snr;
  if (k > 45) {
    k = 45;
  }
  uint8_t bump = (uint8_t)(k * 3 / 2);
  uint16_t r = ((base >> 11) & 0x1F);
  uint16_t g = ((base >> 5) & 0x3F);
  uint16_t b = (base & 0x1F);
  r = (uint16_t)min(31, (int)r + (bump >> 3));
  g = (uint16_t)min(63, (int)g + (bump >> 2));
  b = (uint16_t)min(31, (int)b + (bump >> 3));
  return (uint16_t)((r << 11) | (g << 5) | b);
}

void parseOptionalInt16(const char* p, int16_t& out) {
  if (!p || !*p) {
    out = -1;
    return;
  }
  out = (int16_t)strtol(p, nullptr, 10);
}

double dmToDeg(const char* dm, char dir) {
  if (!dm || !*dm || (dir != 'N' && dir != 'S' && dir != 'E' && dir != 'W')) {
    return NAN;
  }
  double v = strtod(dm, nullptr);
  int deg = (int)(v / 100.0);
  double minutes = v - (double)deg * 100.0;
  double dec = (double)deg + minutes / 60.0;
  if (dir == 'S' || dir == 'W') {
    dec = -dec;
  }
  return dec;
}

void formatUtcFromField(const char* field) {
  if (!field || strlen(field) < 6) {
    strncpy(utcStr, "--:--:--", sizeof(utcStr));
    return;
  }
  int h = (field[0] - '0') * 10 + (field[1] - '0');
  int m = (field[2] - '0') * 10 + (field[3] - '0');
  int s = (field[4] - '0') * 10 + (field[5] - '0');
  snprintf(utcStr, sizeof(utcStr), "%02d:%02d:%02d", h, m, s);
}

void formatDateFromRmc(const char* field) {
  if (!field || strlen(field) < 6) {
    strncpy(dateStr, "--/--/--", sizeof(dateStr));
    return;
  }
  char dd[3] = {field[0], field[1], '\0'};
  char mm[3] = {field[2], field[3], '\0'};
  char yy[3] = {field[4], field[5], '\0'};
  snprintf(dateStr, sizeof(dateStr), "%s/%s/%s", dd, mm, yy);
}

void purgeConstellation(uint8_t sys) {
  int w = 0;
  for (int i = 0; i < rowCount; ++i) {
    if (rows[i].system != sys) {
      rows[w++] = rows[i];
    }
  }
  rowCount = w;
}
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
